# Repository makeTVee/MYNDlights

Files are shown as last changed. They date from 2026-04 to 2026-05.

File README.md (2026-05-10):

# MYNDlights

Addressable LED mod with custom 3D-printed front panels for the [Teufel MYND](https://github.com/teufelaudio/mynd-hardware) open-source Bluetooth speaker. Runs WLED on an ESP32-S3 with audio-reactive effects driven by I2S bus sniffing.

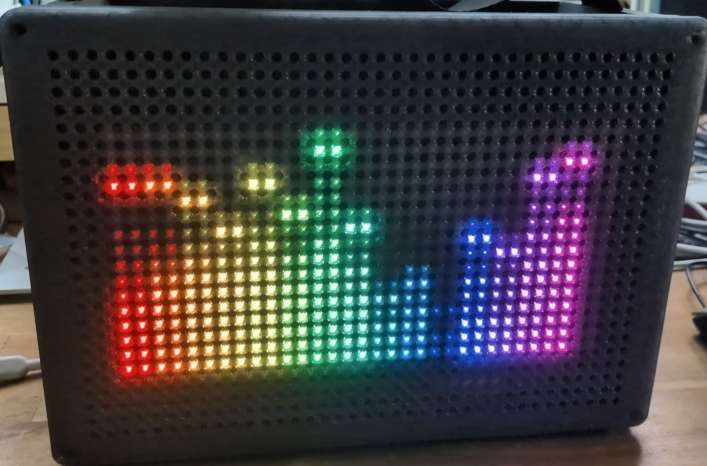
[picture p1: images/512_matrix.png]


[Demo (YouTube)](https://youtube.com/shorts/J1kN-PWX2cs)

---

## How It Works

The ESP32-S3 operates as an **I2S slave**, passively sniffing the I2S data line between the MYND's Bluetooth module and its amplifier. This enables audio-reactive LED effects without any active signal interception or modification to the audio path.

WLED was recompiled with the generic I2S driver configured in slave mode to make this work.

A custom flex PCB taps the I2S connector on the mainboard — no soldering required (see [Installation](#installation)).

---

## Hardware

| Component | Details |
|---|---|
| MCU | Seeed XIAO ESP32-S3 |
| LEDs | WS2812B (NeoPixel-compatible) |
| Wiring | FFC cables (6-wire flex for LED power + data) |
| Interface | Custom flex PCB + rigid carrier PCB |

---

## Variants

### Ring — 40 LEDs
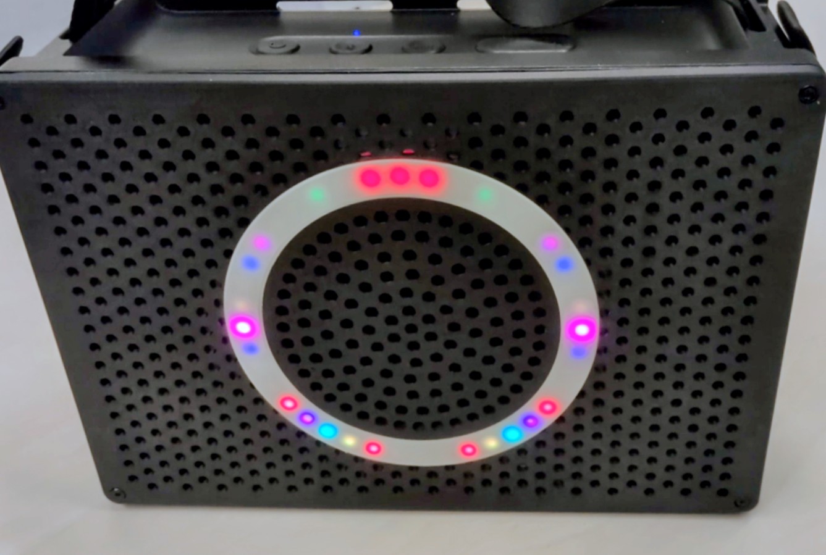
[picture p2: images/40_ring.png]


### Ring — Teufel Logo
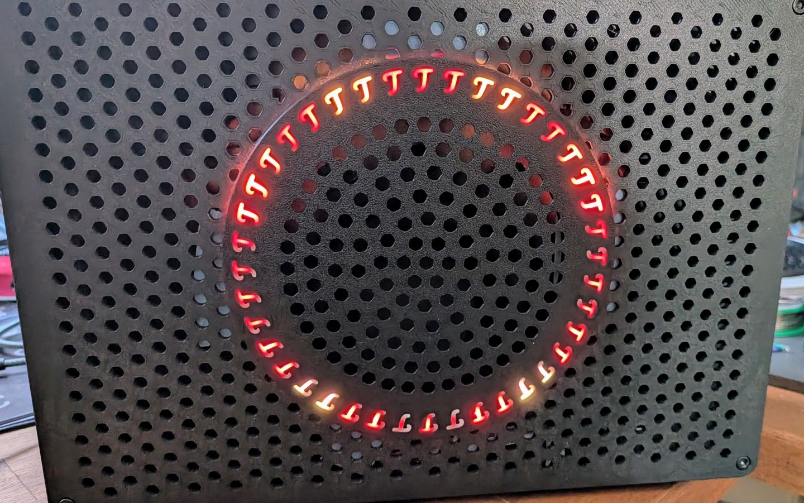
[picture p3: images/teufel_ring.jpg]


### Ring — 100 LEDs
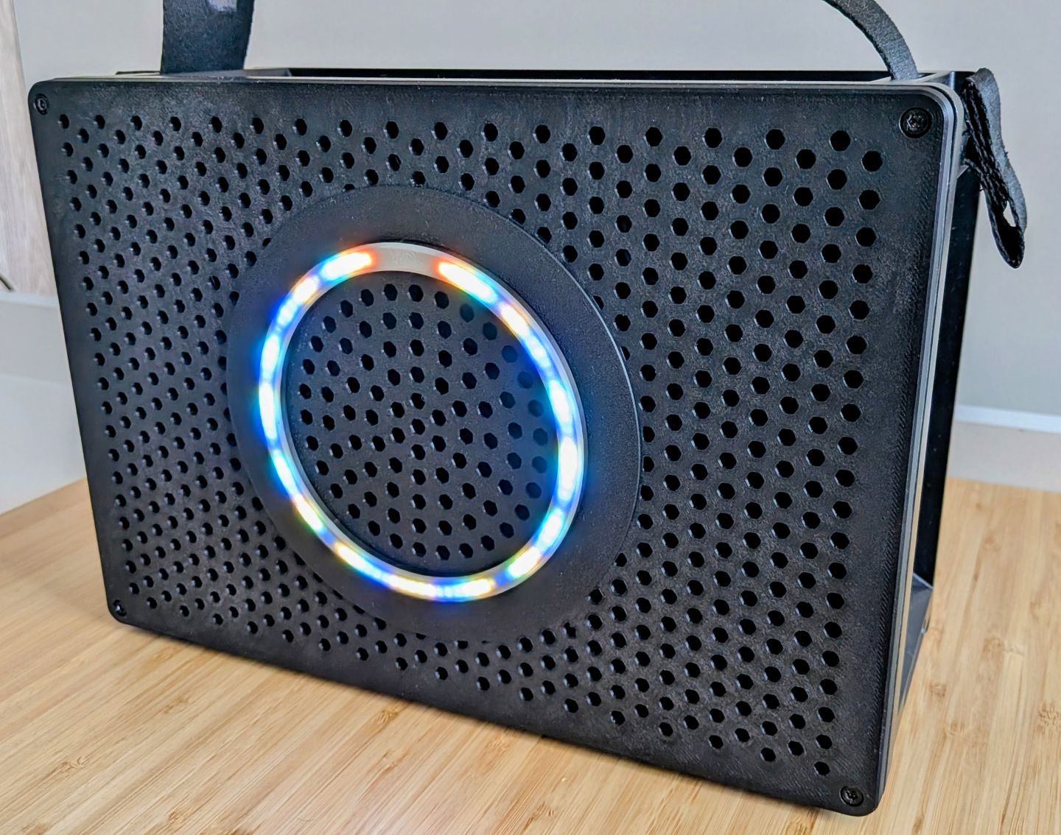
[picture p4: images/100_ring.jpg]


### Matrix — 512 LEDs (32×16)

Transparent LED matrix mounted behind the speaker grille, LEDs placed between the grille holes.

CAD drawing

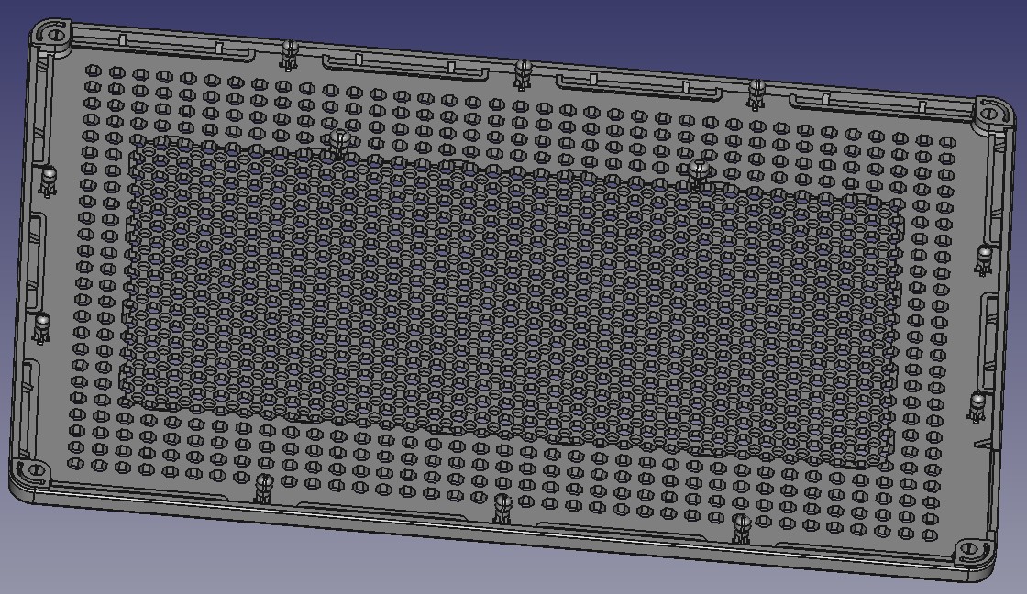
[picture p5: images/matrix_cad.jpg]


Installed Matrix PCB

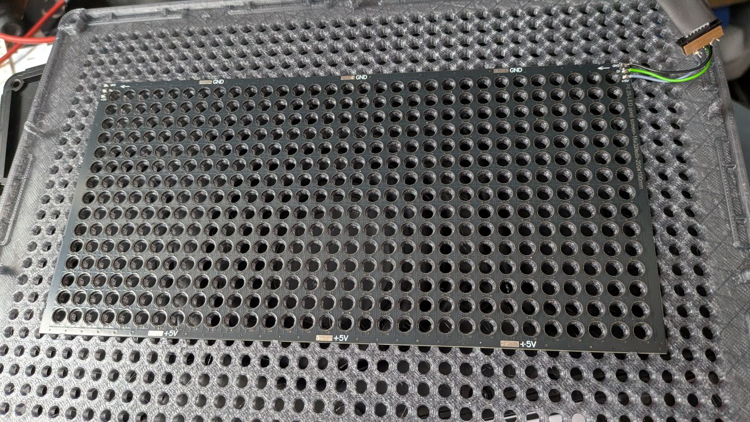
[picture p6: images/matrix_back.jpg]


Front with the LEDs

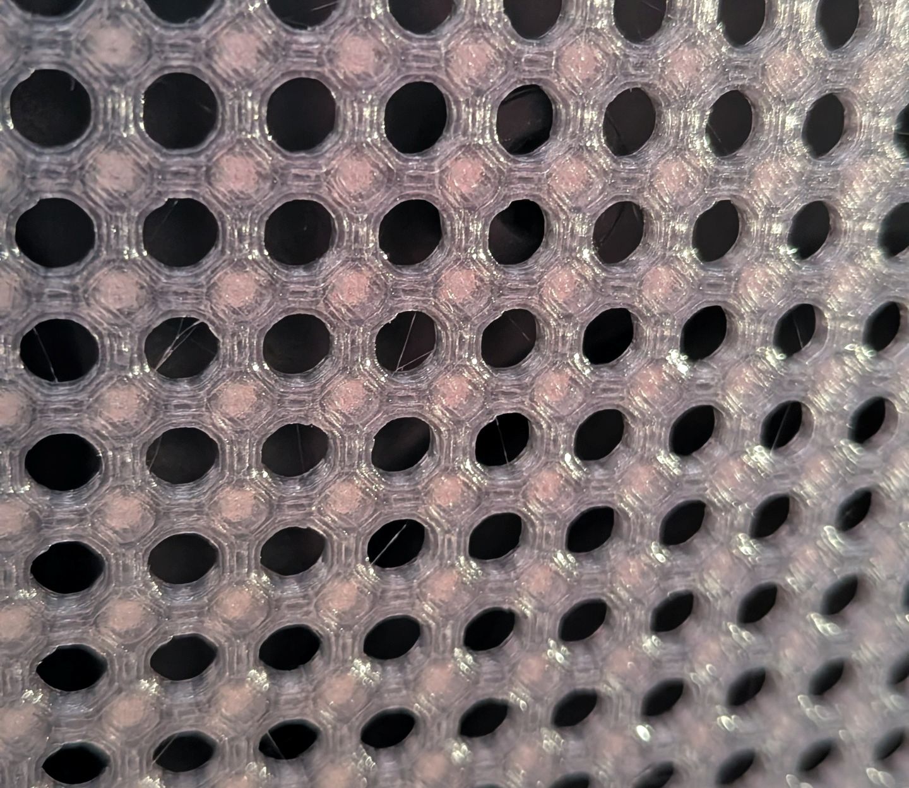
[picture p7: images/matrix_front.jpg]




---

## Installation

### PCB

Custom PCBs handle I2S signal tapping and 5V power distribution for the ESP32-S3.

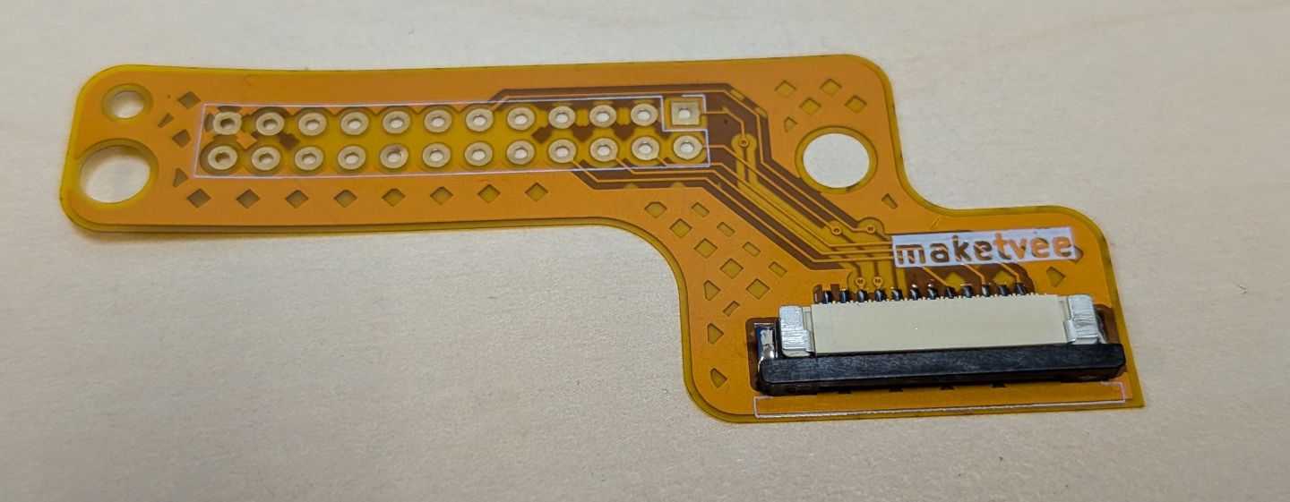
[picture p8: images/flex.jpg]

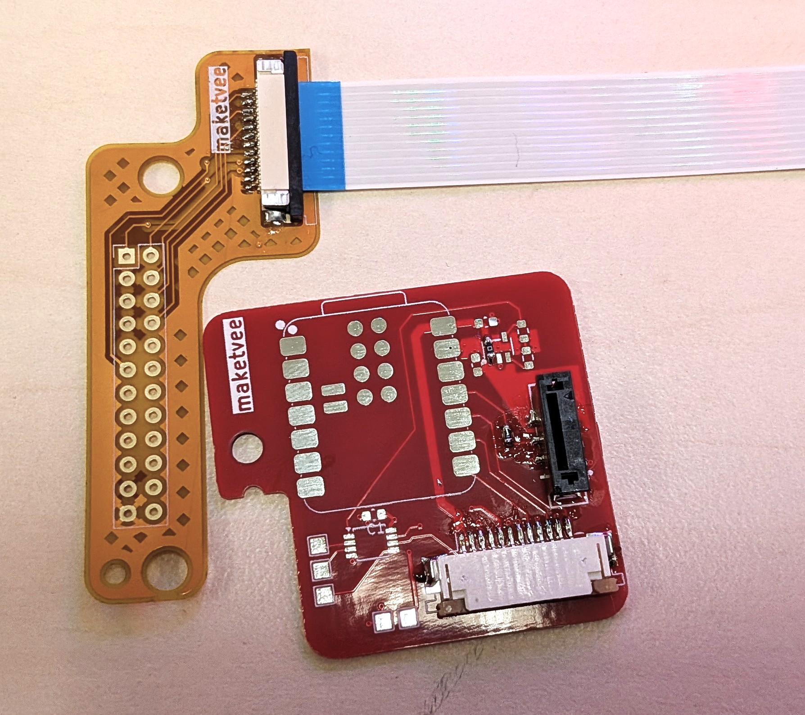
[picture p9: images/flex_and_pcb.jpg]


The flex PCB is dimensioned so its holes are slightly undersized relative to the mainboard connector. No soldering needed — press-fit and secure with the two existing screws.

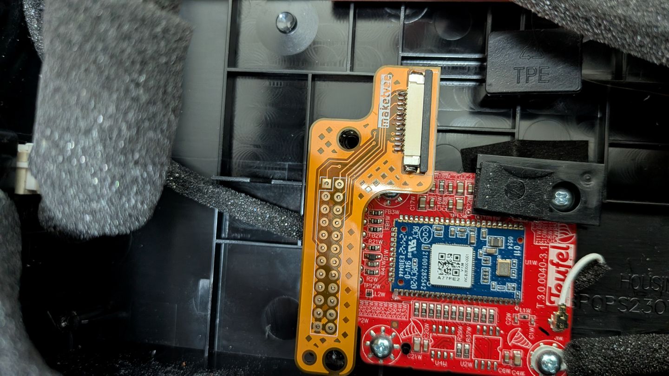
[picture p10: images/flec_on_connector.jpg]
Flex installation


The subwoofer blocks direct routing near the connector, so signals are carried via FFC cable to the upper-right corner of the enclosure.

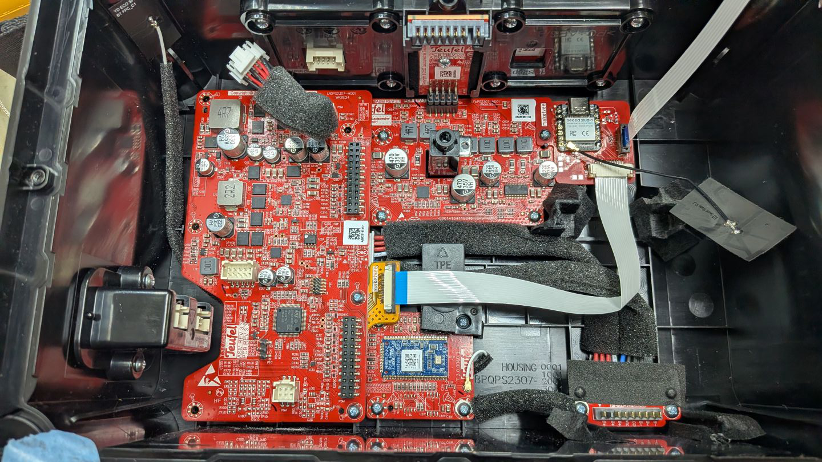
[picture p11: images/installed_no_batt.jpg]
PCBs installed without battery


The LED harness uses a 6-wire flex cable (2× 5V, 2× GND, 2× DATA).

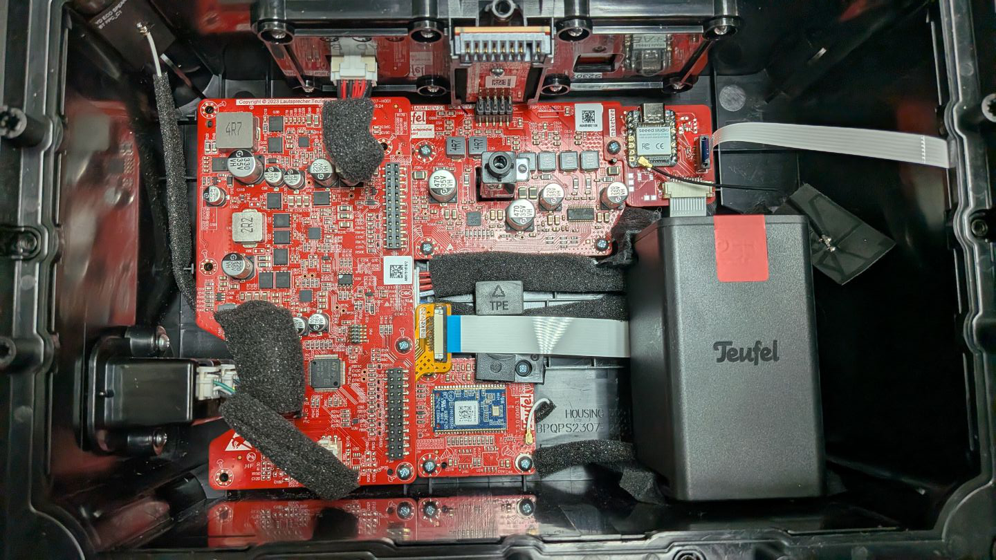
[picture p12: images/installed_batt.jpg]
PCBs installed with battery


> **Future work:** Low-battery LED shutoff via STM32 I2C interface.

---

## Repository Structure

```
MYNDlights/
├── CAD/      # 3D models for front panels
└── Kicad/    # PCB schematics and layout
```

---

## License

BSD 2-Clause "Simplified" License.

## References

- [Teufel MYND hardware repo](https://github.com/teufelaudio/mynd-hardware)

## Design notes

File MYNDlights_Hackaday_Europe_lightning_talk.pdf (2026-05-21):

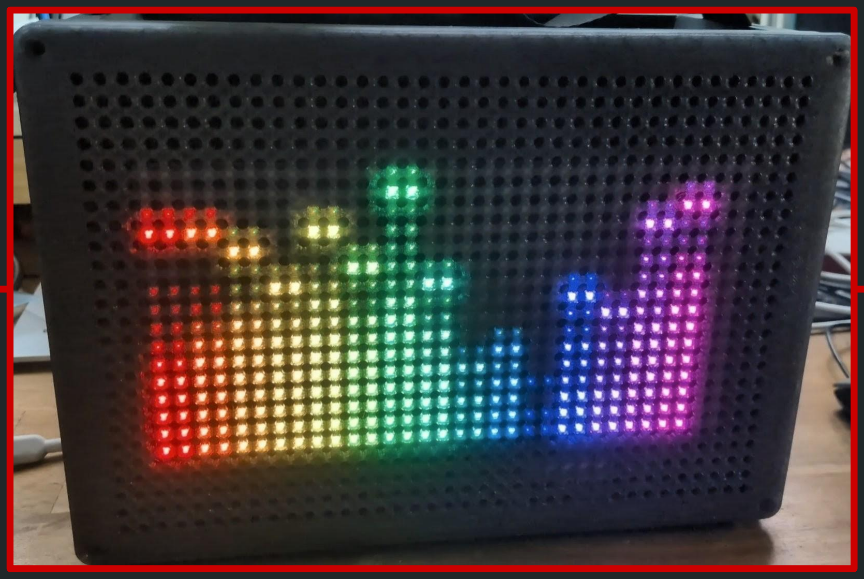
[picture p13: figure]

# Project MYNDlights

## Modding an open-source speaker

## maketvee

## Teufel MYND Bluetooth speaker

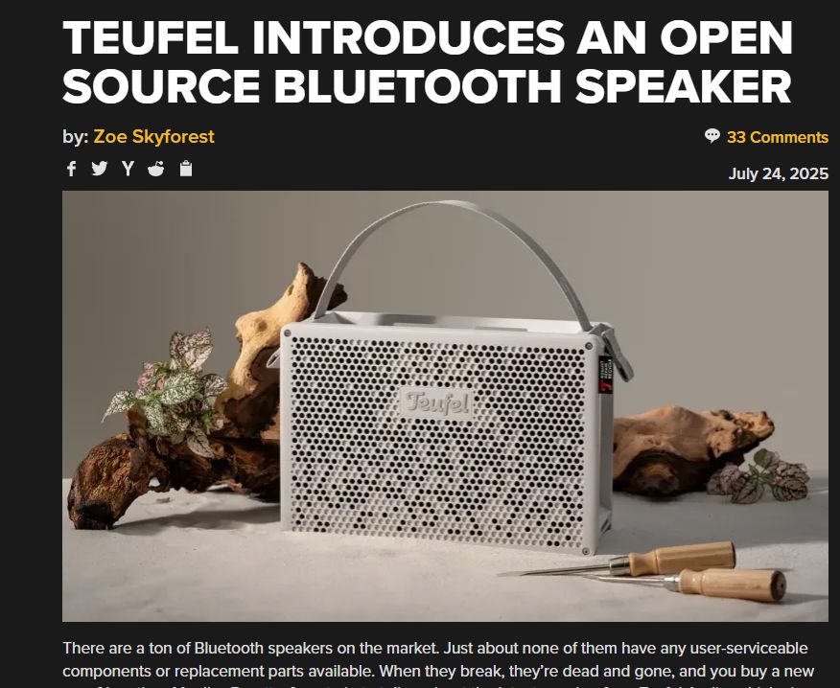
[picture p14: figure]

- 2.1 Bluetooth speaker
- Cradle to Cradle Certified
- IP67
- Party Link
- 200-250€

## Teufel MYND

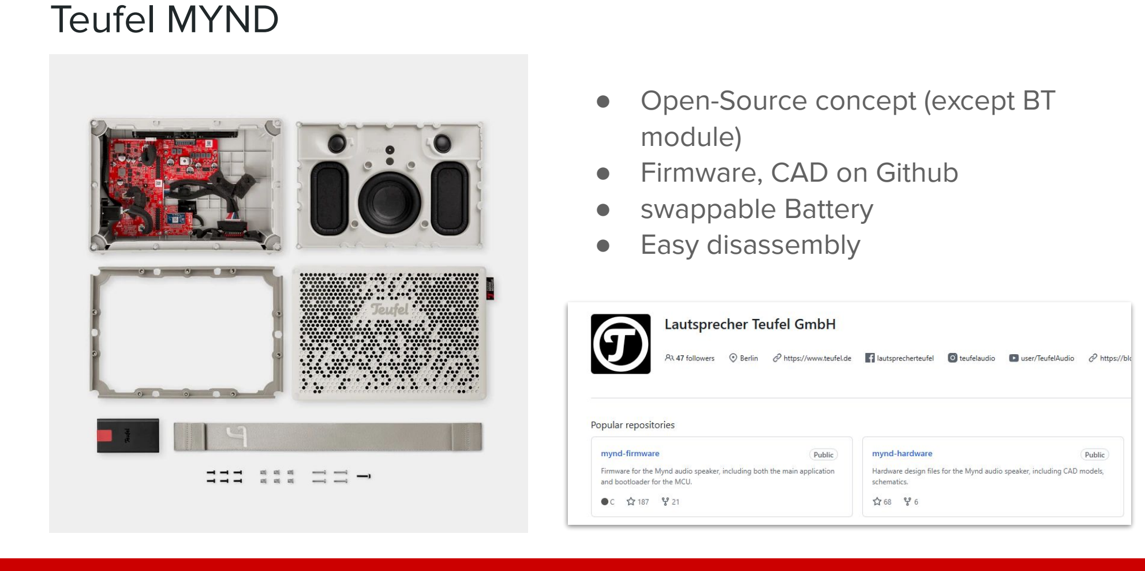
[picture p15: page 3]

- Open-Source concept (except BT module)
- Firmware, CAD on Github
- swappable Battery
- Easy disassembly

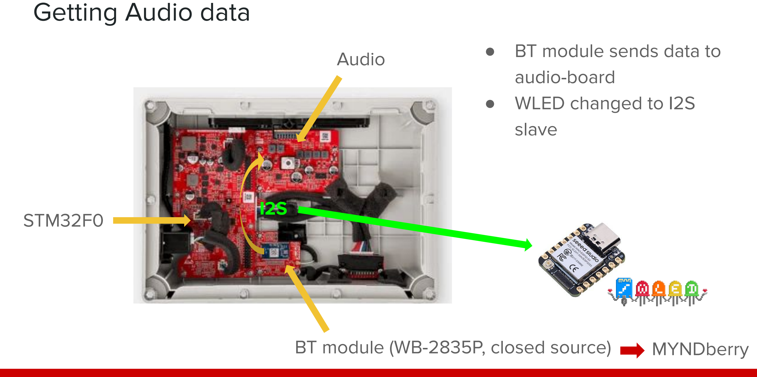
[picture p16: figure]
Getting Audio data; STM32F0; BT module (WB-2835P, closed source); Audio; ● BT module sends data to; audio-board ● WLED changed to I2S slave; MYNDberry

## Integration

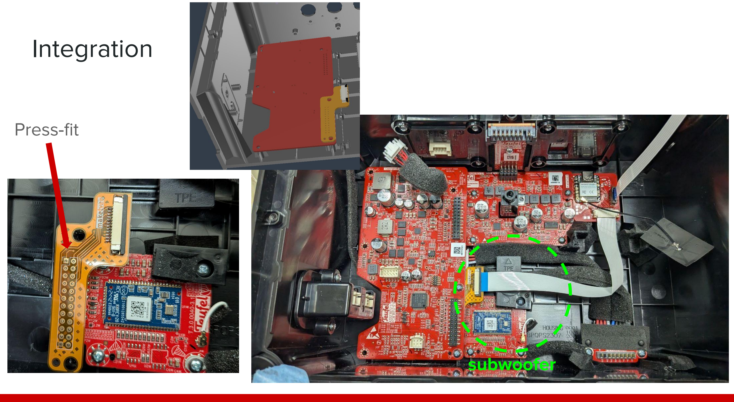
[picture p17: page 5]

Press-fit

subwoofer

## Integration

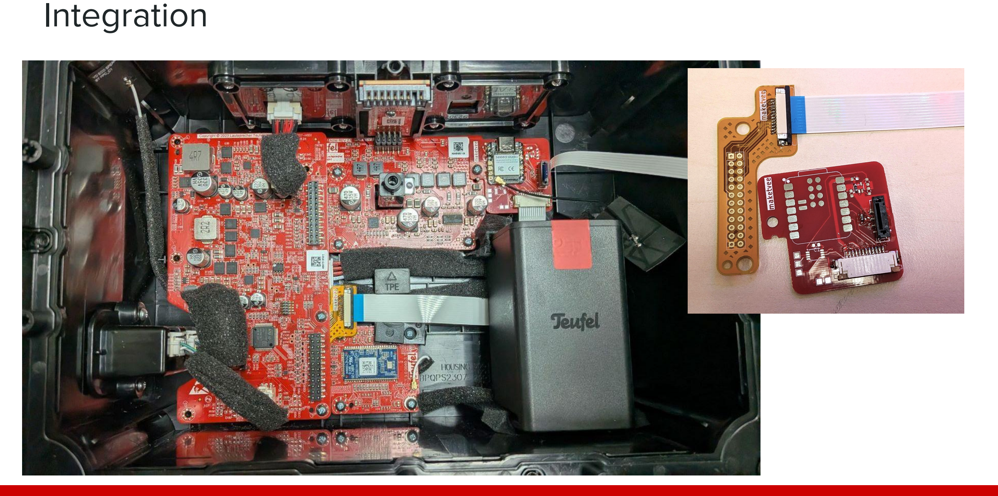
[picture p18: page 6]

## Lights on

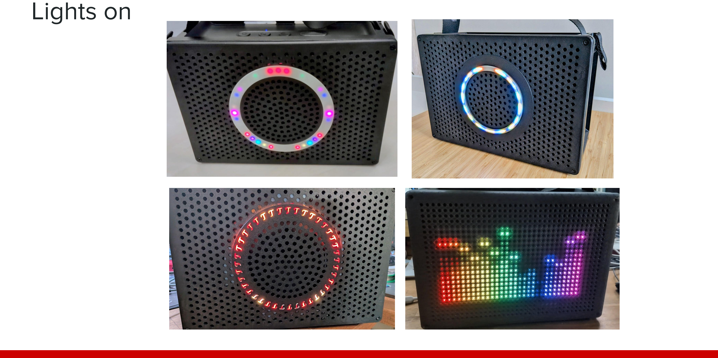
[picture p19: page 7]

## Lights on

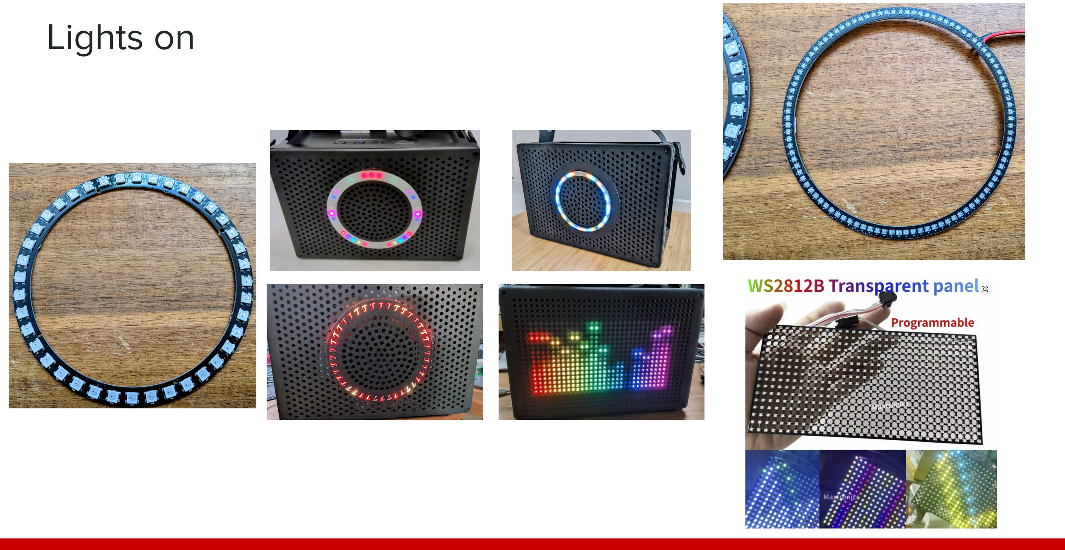
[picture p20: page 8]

## Matrix integration

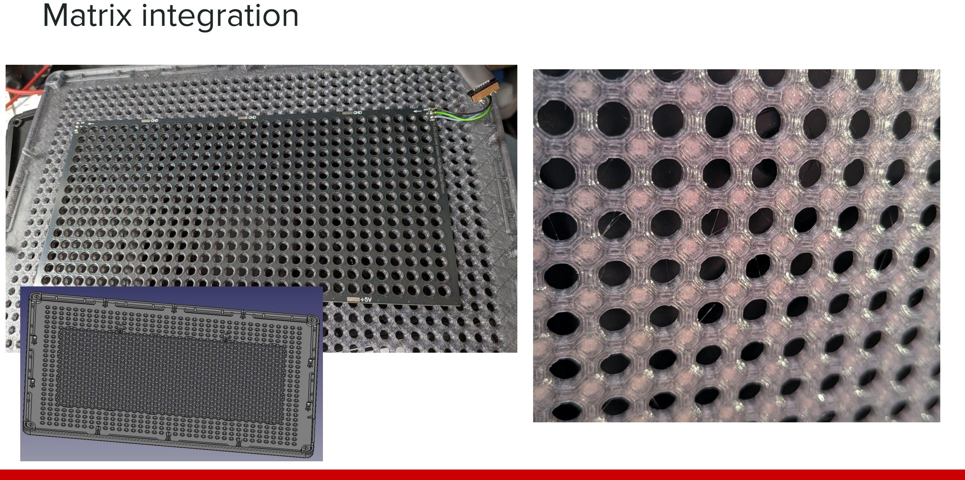
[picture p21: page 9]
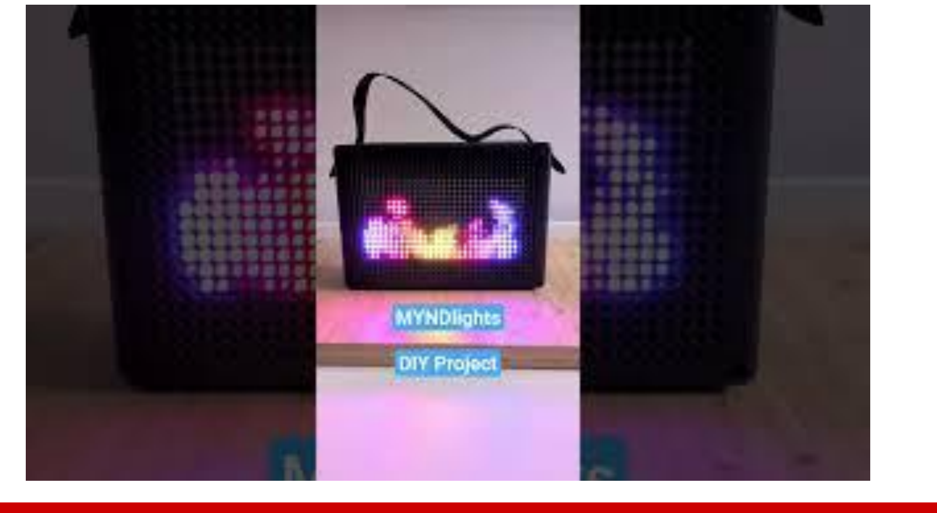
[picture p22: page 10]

## Github

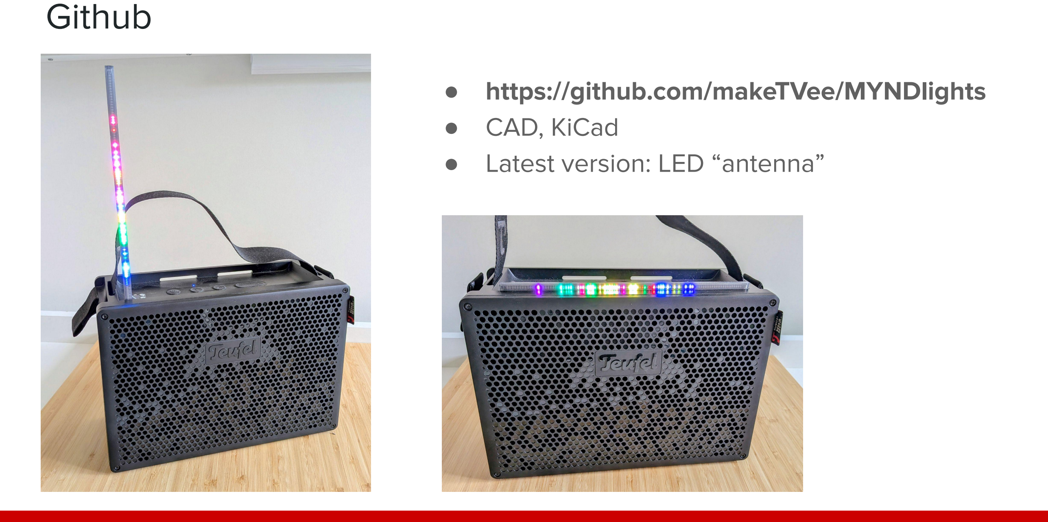
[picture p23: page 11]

- https://github.com/makeTVee/MYNDlights
- CAD, KiCad
- Latest version: LED “antenna”

## Open tasks:

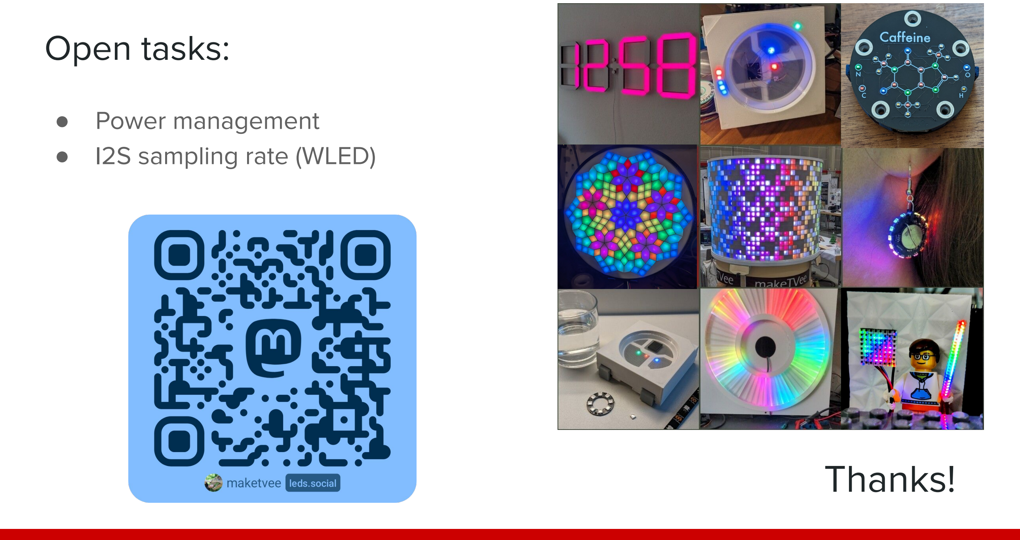
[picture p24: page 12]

- Power management
- I2S sampling rate (WLED)

## Thanks!

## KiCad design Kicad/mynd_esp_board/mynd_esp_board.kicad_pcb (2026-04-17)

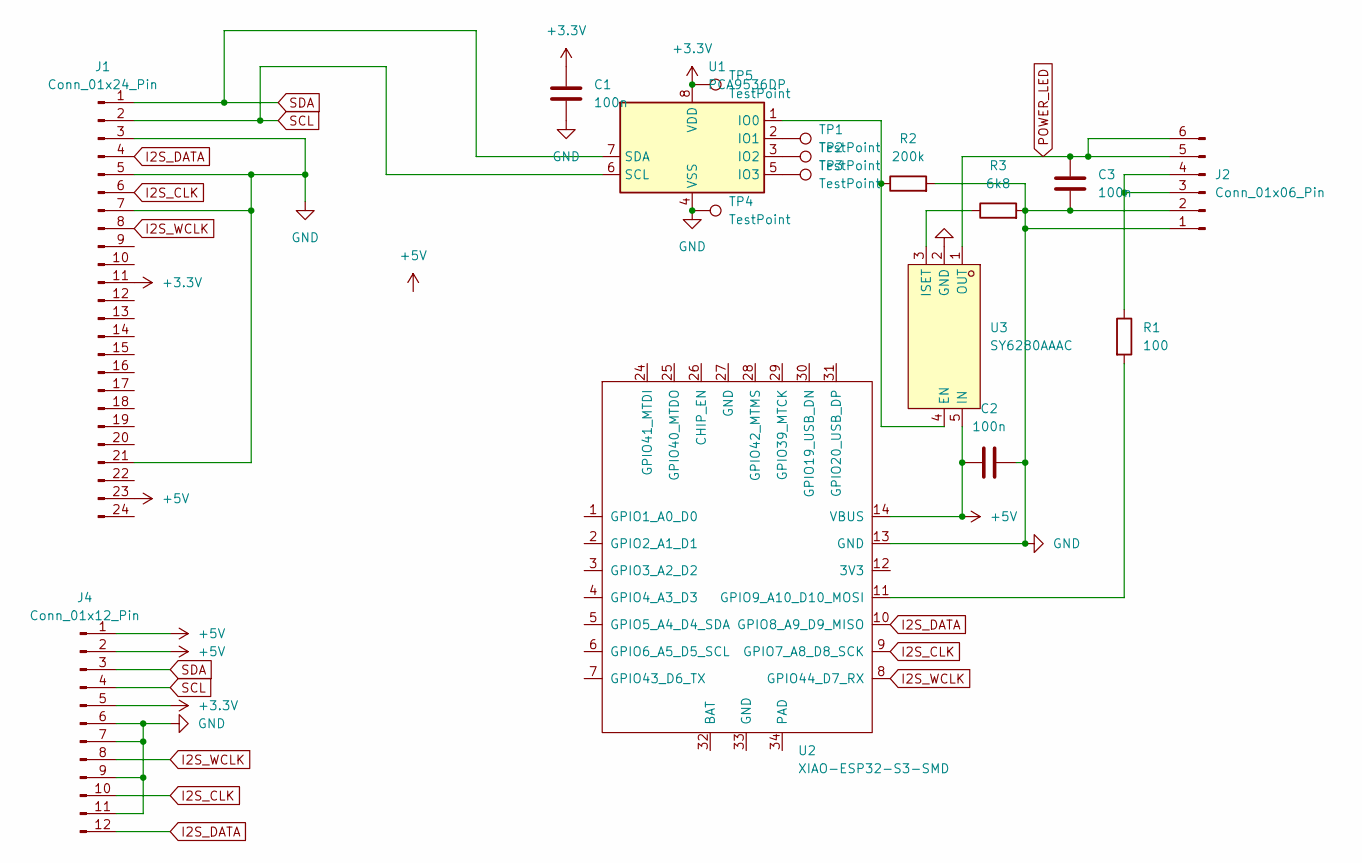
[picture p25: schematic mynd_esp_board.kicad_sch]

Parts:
C1, C2, C3: 100n; C_0603_1608Metric
J1: Conn_01x24_Pin
J2: Conn_01x06_Pin; FPC-SMD_F1003-ZV-06-25T-R
J4: Conn_01x12_Pin; TE_1-84953-2_1x12-1MP_P1.0mm_Horizontal
R1: 100; R_0603_1608Metric
R2: 200k; R_0603_1608Metric
R3: 6k8; R_0603_1608Metric
TP1, TP2, TP3, TP4, TP5: TestPoint; TestPoint_Pad_1.5x1.5mm
U1: PCA9536DP; TSSOP-8_3x3mm_P0.65mm
U2: XIAO-ESP32-S3-SMD
U3: SY6280AAAC; TSOT-23-5_L2.9-W1.6-P0.95-LS2.8-BL; LCSC Part C207620

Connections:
+3.3V: C1.1, J1.11, J4.5, TP5.1, U1.8 (VDD)
+5V: C2.2, J1.23, J4.1, J4.2, U2.14 (VBUS), U3.5 (IN)
GND: C1.2, C2.1, C3.2, J1.3, J1.5, J1.7, J1.21, J2.1, J2.2, J4.6, J4.7, J4.9, J4.11, R2.2, R3.2, TP4.1, U1.4 (VSS), U2.13 (GND), U3.2 (GND)
I2S_CLK: J1.6, J4.10, U2.9 (GPIO7_A8_D8_SCK)
I2S_DATA: J1.4, J4.12, U2.10 (GPIO8_A9_D9_MISO)
I2S_WCLK: J1.8, J4.8, U2.8 (GPIO44_D7_RX)
unnamed: J2.3, J2.4, R1.1
unnamed: R2.1, U1.1 (IO0), U3.4 (EN)
unnamed: TP1.1, U1.2 (IO1)
unnamed: TP2.1, U1.3 (IO2)
unnamed: TP3.1, U1.5 (IO3)
unnamed: R1.2, U2.11 (GPIO9_A10_D10_MOSI)
unnamed: R3.1, U3.3 (ISET)
POWER_LED: C3.1, J2.5, J2.6, U3.1 (OUT)
SCL: J1.2, J4.4, U1.6 (SCL)
SDA: J1.1, J4.3, U1.7 (SDA)

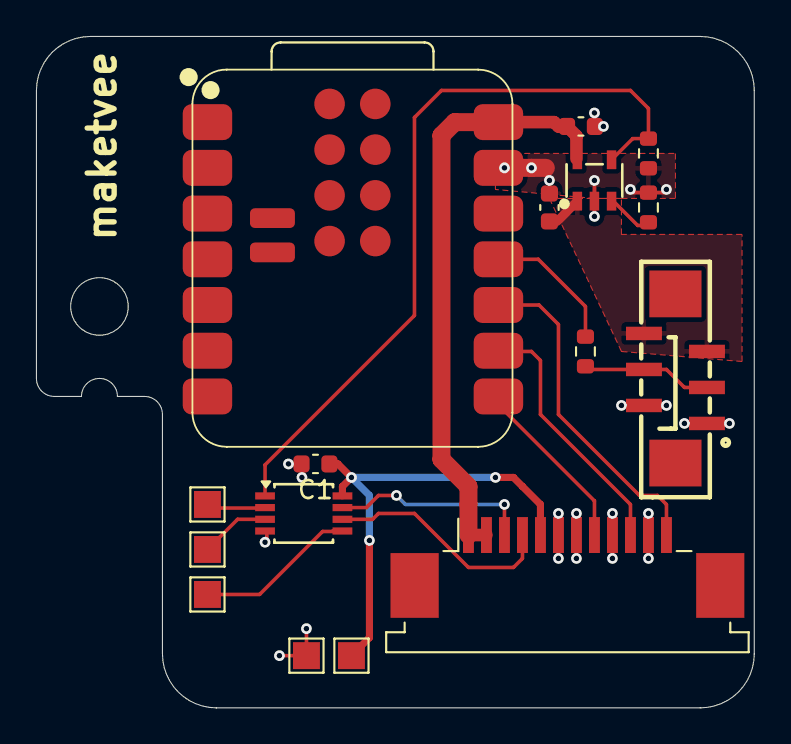
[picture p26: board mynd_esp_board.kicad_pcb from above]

Board: 2 copper layers, 39.9 x 37.3 mm, 16 parts (0 on the bottom side), 16 nets.

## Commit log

2026-04-17 file commit
    [mynd_esp_board.kicad_pcb, mynd_esp_board.kicad_sch, mynd_flex.kicad_pcb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]
2026-04-19 Revise README for Teufel MYND and installation details
    Updated product name to 'Teufel MYND' and clarified ESP32-S3 details. Added information about custom PCBs and installation specifics.
2026-04-19 Update README with PCB installation details
    Added information about custom PCBs for I2S data and powering the ESP, along with installation details.
2026-04-21 added cad image
2026-04-21 Update README with images of matrix components
    Added images for CAD drawing and installed matrix PCB.
